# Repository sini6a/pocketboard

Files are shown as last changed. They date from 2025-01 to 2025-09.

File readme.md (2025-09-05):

# Pocketboard

### A Pocket-Friendly On-the-Go Keyboard 🖲️

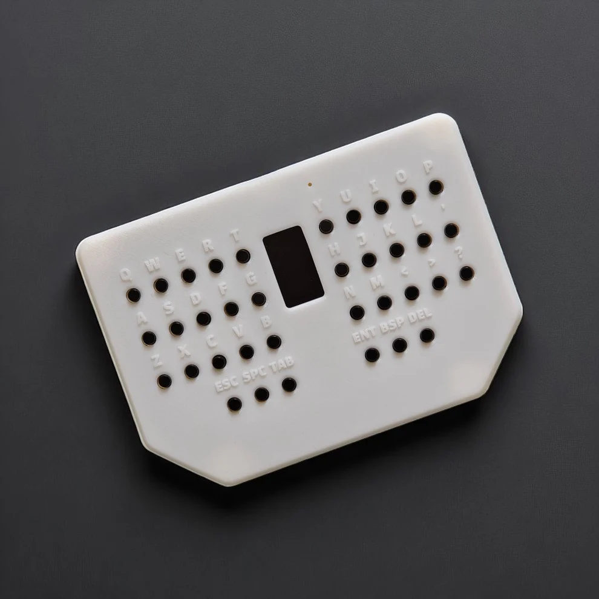
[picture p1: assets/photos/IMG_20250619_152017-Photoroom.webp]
Photo of the keyboard #1

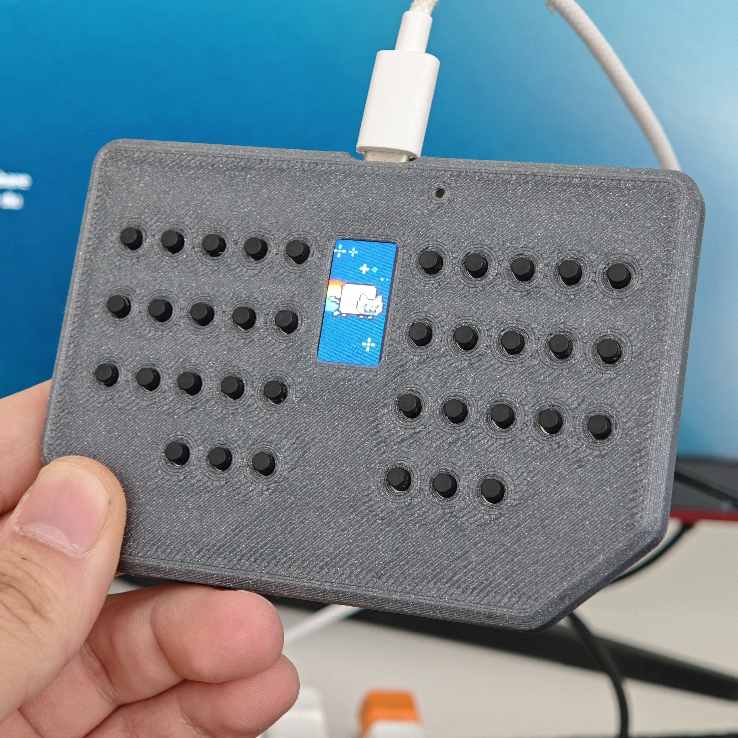
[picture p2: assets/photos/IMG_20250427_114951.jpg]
Photo of the keyboard #2


**Pocketboard** is a compact, versatile keyboard designed for IT technicians and professionals who need a portable and efficient input device.

**NOTE:** If you are building this keyboard and want to use KMK make sure to flash MicroPython for [Adafruit Feather RP2040](https://micropython.org/download/ADAFRUIT_FEATHER_RP2040/). After flashing just copy and paste the firmware located in the `firmware/kmk` folder. I recommend using the QMK firmware instead of KMK.

## Progress List:

- [x] Firmware: Home row mods!
- [x] Firmware: Layers
- [x] Firmware: LED Control (On/Off)
- [x] Hardware & Firmware: LCD!
- [x] 3D: Case Design

## Features

- **USB Type-C Connector**: Modern and reliable connection for seamless usage.
- **Miryoku Layout**: Optimized for productivity and efficient typing.
- **LEDs and Display**: Equipped with programmable LEDs and a display which shows pressed key and small animation when idle.

## What's New?

Pocketboard builds upon the original **HandiPi** design with several upgrades and enhancements:

- **ATMega328 replaced with RP2040**: Improved performance and more flexibility with the powerful RP2040 microcontroller.
- **LEDs for Illumination**: Added for better visibility.
- **USB Type-C Connector**: Ensures ease of connectivity and compatibility with modern devices.
- **LCD Support**: Added support for an LCD display for dynamic functionality. Tested and fully operational!
- **SMD Components**: Transitioned from through-hole components to SMD for a more compact design.

## Why Pocketboard?

Pocketboard is crafted for those who are often on the move, combining portability with practicality. Whether you're debugging systems or managing configurations, this handy keyboard ensures you're always prepared and comes handy to keep in your cargo pants or in your car.

## Project Structure

The project repository is structured as follows:

- **`kicad/`**: Contains PCB design files and schematics.
- **`gerbers/`**: Includes Gerber files essential for manufacturing.
- **`fimware/qmk`**: Includes Pocketboard firmware files. This folder should be copied to `qmk_firmware/keyboards`  before compiling.
- **`fimware/kmk`**: Includes Pocketboard firmware files. This folder should be copied to your keyboard after flashing MicroPython. (Not fully implemented!)

The schematic is available in PDF format in the `kicad/` directory.

## Credits

Pocketboard is inspired by the **HandiPi** project by [brickbots](https://github.com/brickbots).

## Contributing

We welcome contributions from the community! If you’re interested in helping with development, please:

1. Open an issue to discuss your ideas or proposed changes.
2. After discussion, submit a pull request (PR) with your contribution.

Your feedback and suggestions are invaluable in making Pocketboard even better!

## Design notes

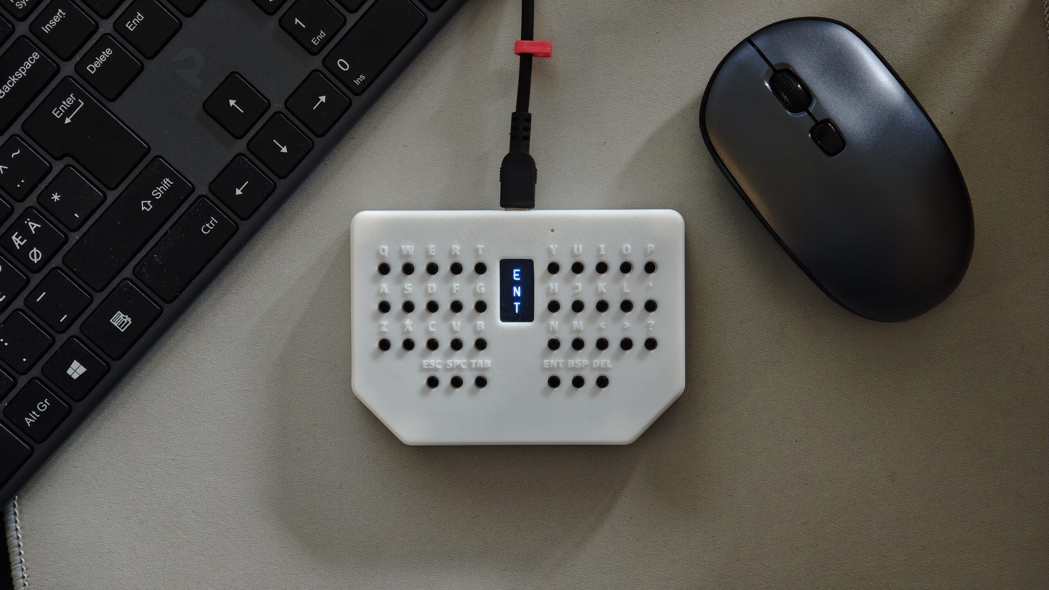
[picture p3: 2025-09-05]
assets/photos/IMG_20250607_135502-scaled.jpg

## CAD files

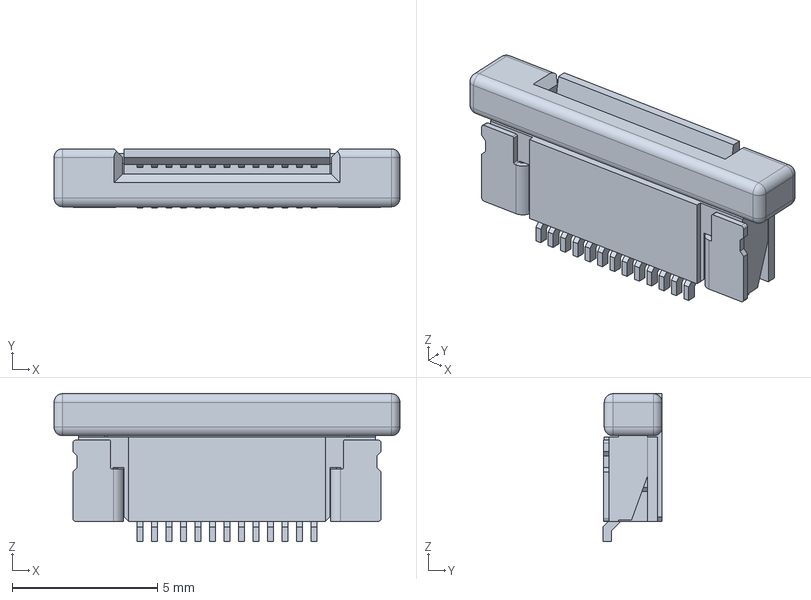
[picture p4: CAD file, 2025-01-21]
kicad/assets/models/1-1734839-3.stp
11.9 x 2.05 x 5.11 mm

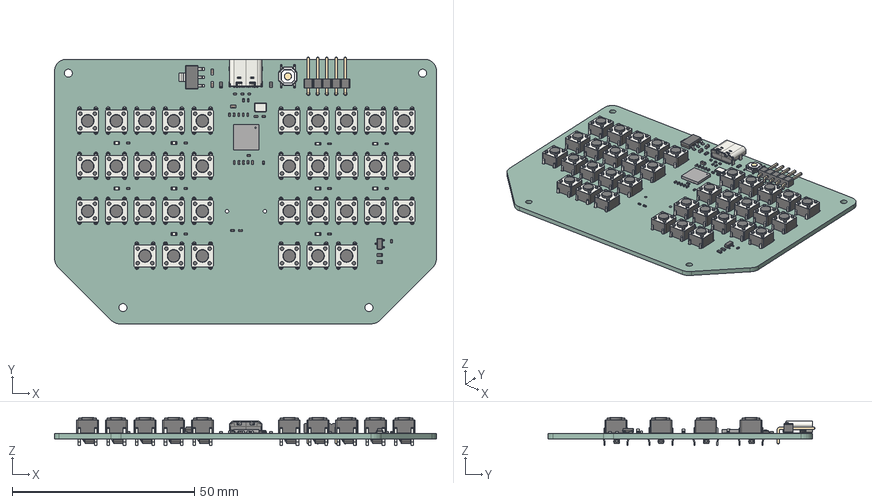
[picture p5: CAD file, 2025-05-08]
kicad/pocketboard.step
104.9 x 73.3 x 7.80 mm
R_0603_1608Metric x 4
SW_PUSH_6mm x 36
C_0402_1005Metric x 14
PinHeader_1x05_P2.54mm_Horizontal
LED_0603_1608Metric x 10
Crystal_SMD_3225-4Pin_3.2x2.5mm
R_0402_1005Metric x 15
D_SOD-923 x 3
C_0603_1608Metric x 3
USB_C_Receptacle_GCT_USB4105-xx-A_16P_TopMnt_Horizontal
QFN-56-1EP_7x7mm_P0.4mm_EP3.2x3.2mm
SOT-223
SOT-23
TS-1187A
D_SOD-123 x 36
pocketboard_PCB

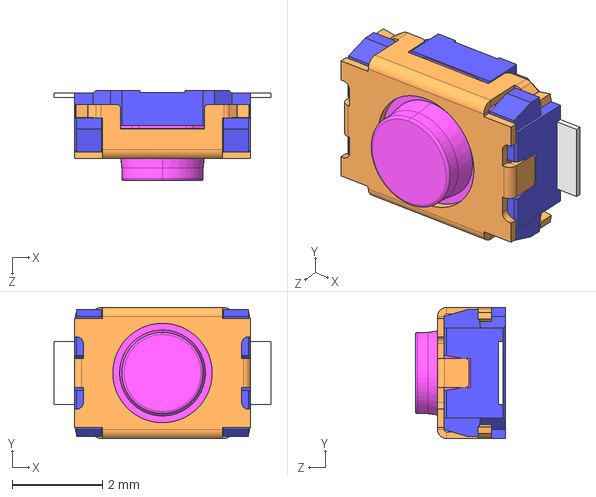
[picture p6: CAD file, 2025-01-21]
kicad/assets/models/SKRKAE.STEP
4.80 x 2.90 x 2.00 mm

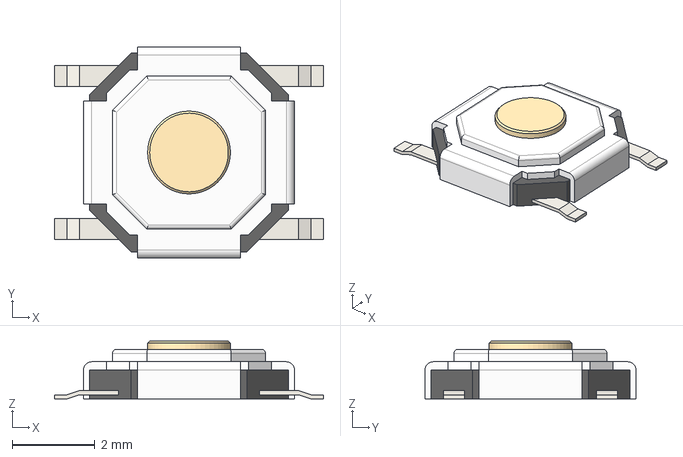
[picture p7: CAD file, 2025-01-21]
kicad/assets/models/TS-1187A.step
6.50 x 5.10 x 1.40 mm

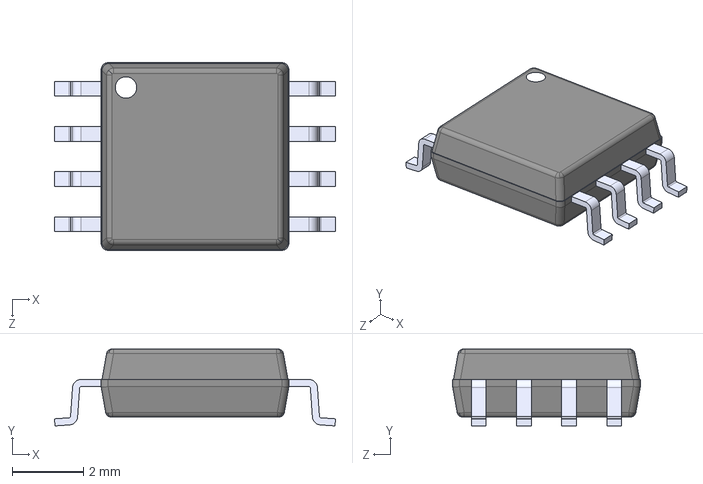
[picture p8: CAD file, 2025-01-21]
kicad/assets/models/W25Q128JVSIQ.STEP
7.90 x 2.16 x 5.28 mm

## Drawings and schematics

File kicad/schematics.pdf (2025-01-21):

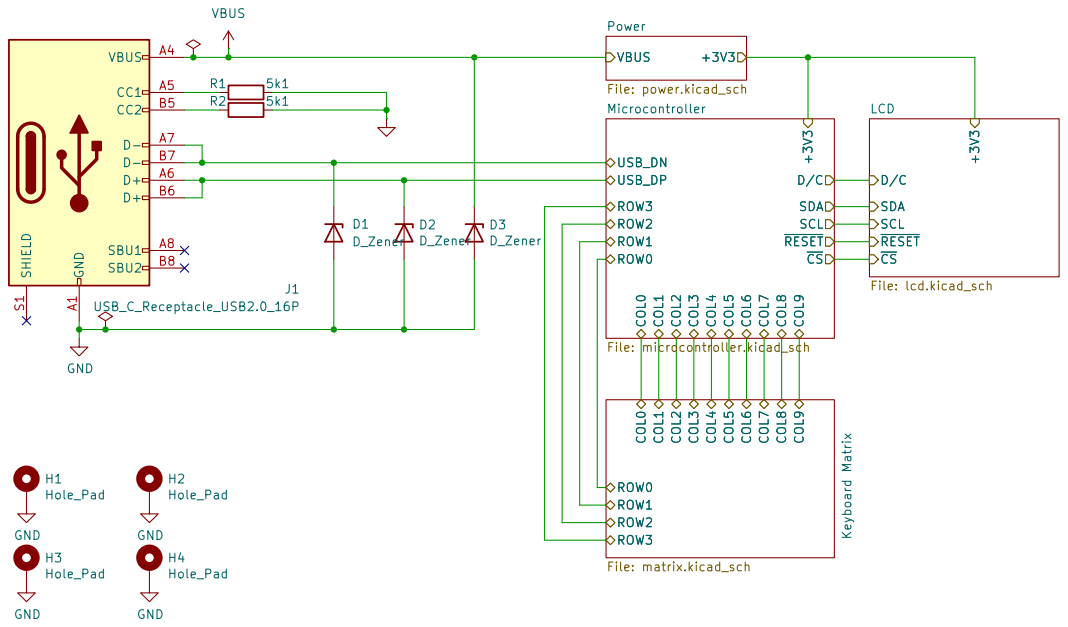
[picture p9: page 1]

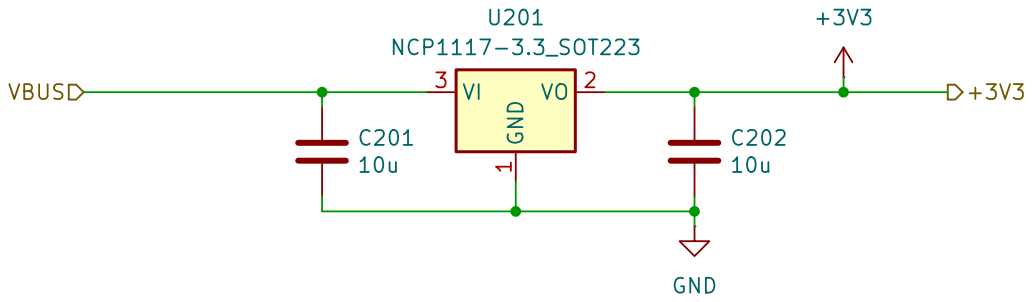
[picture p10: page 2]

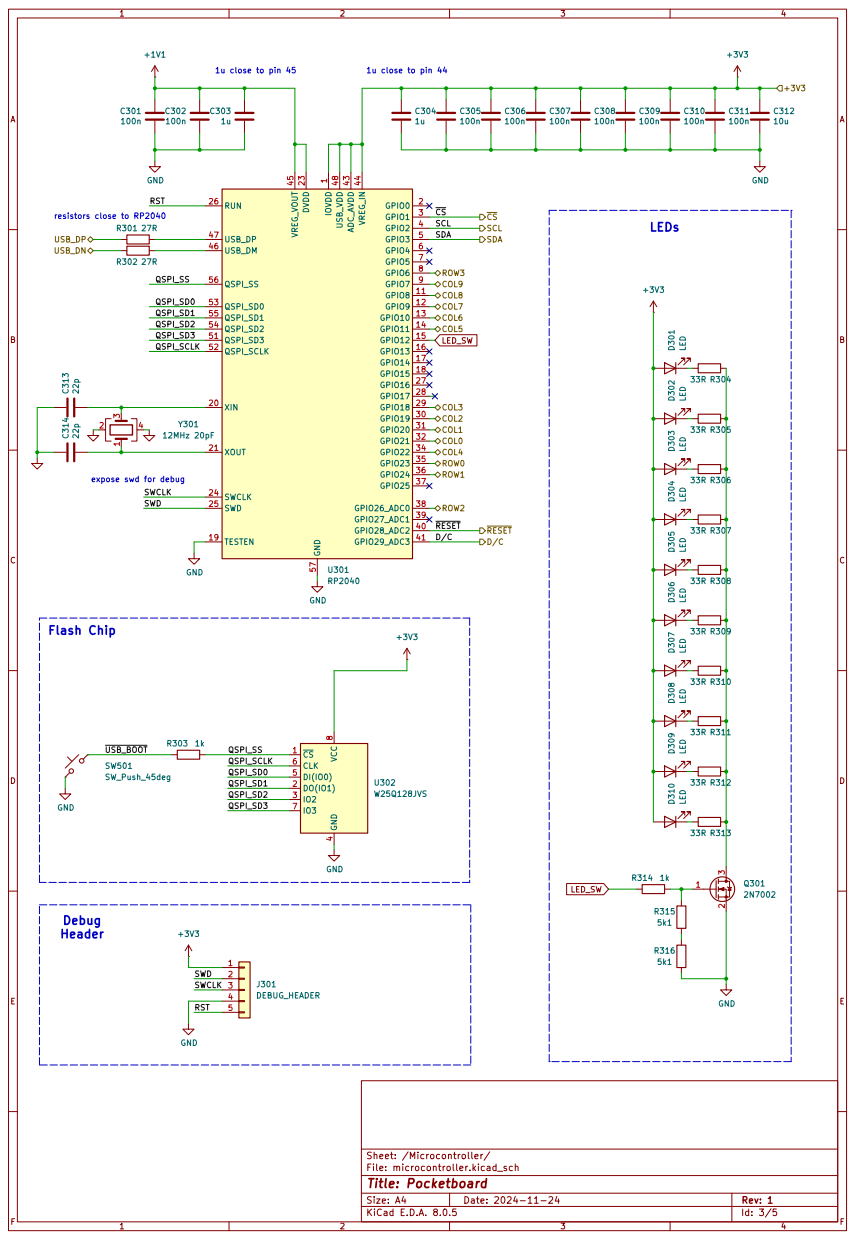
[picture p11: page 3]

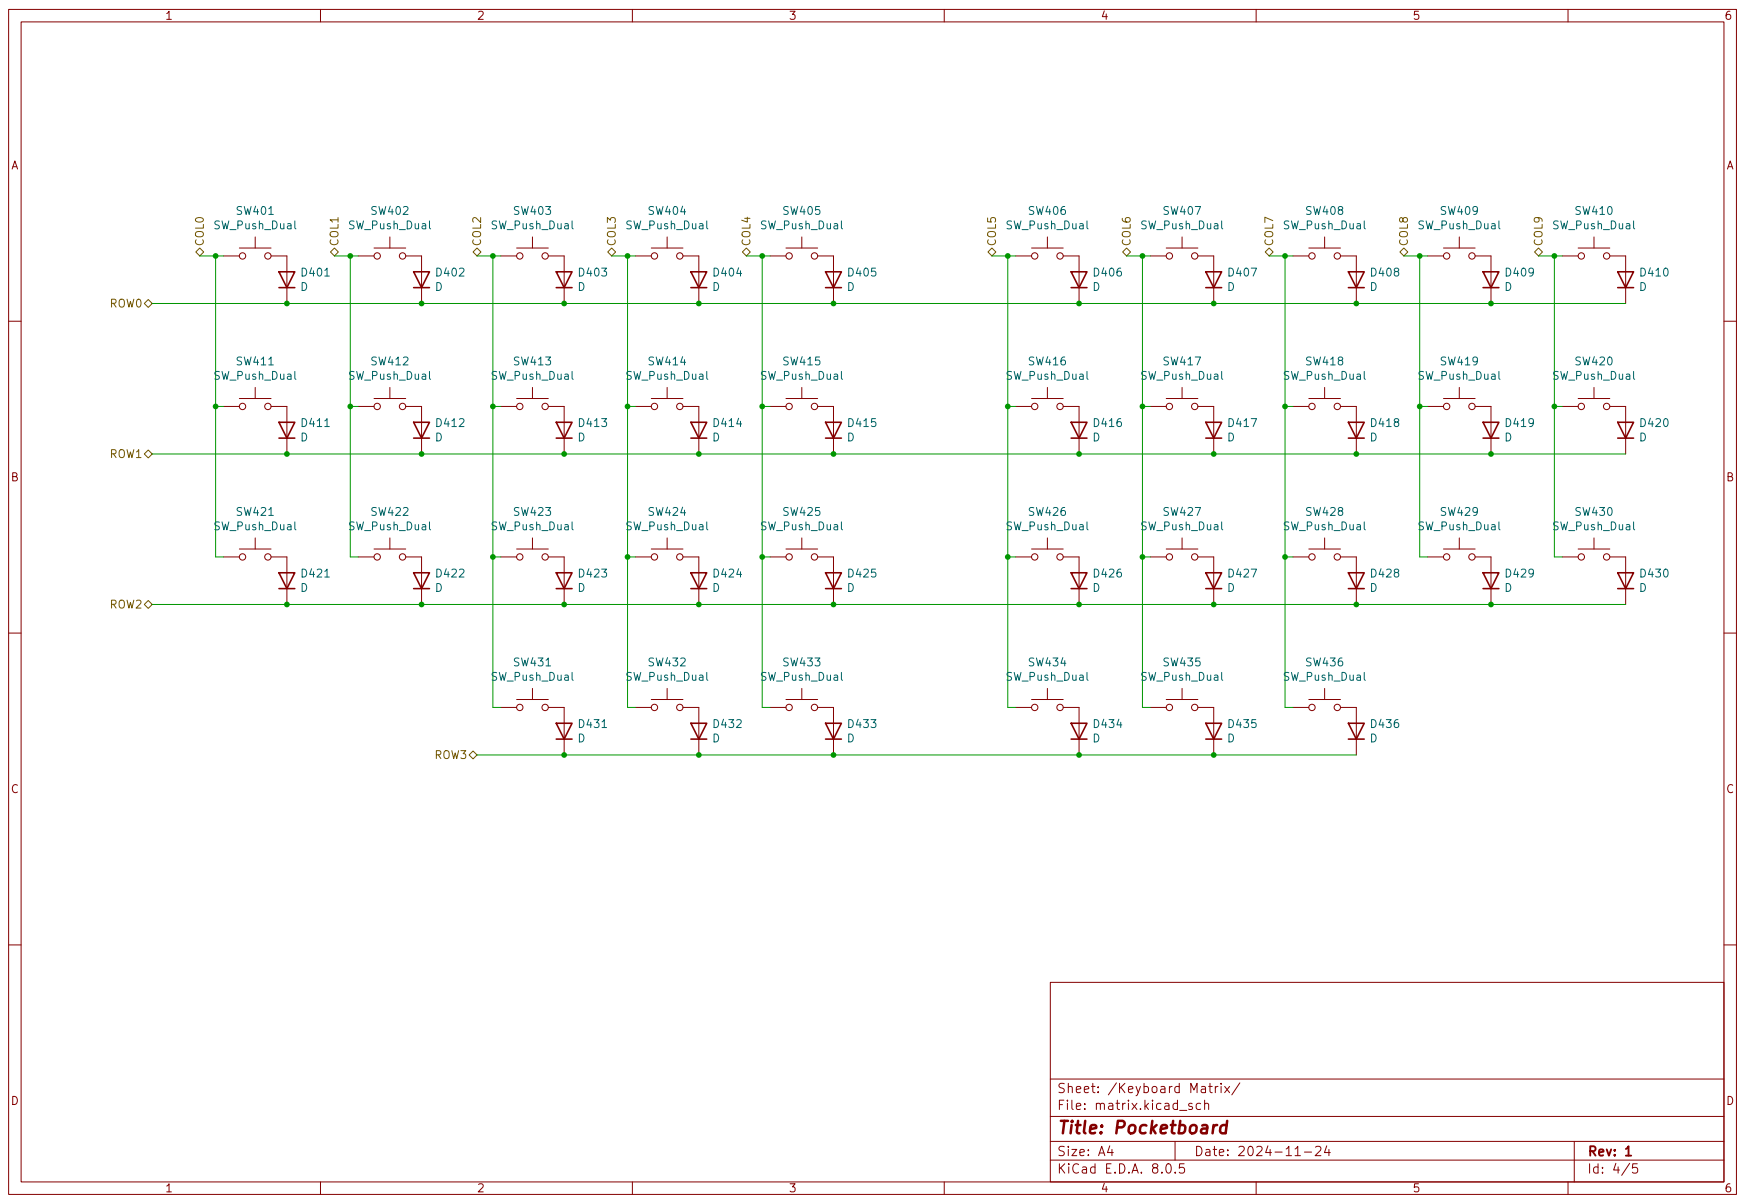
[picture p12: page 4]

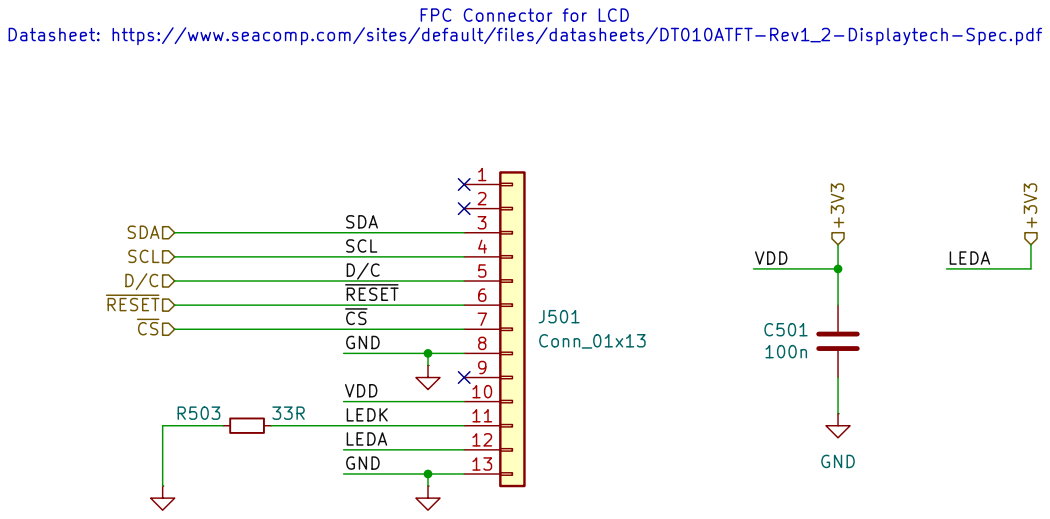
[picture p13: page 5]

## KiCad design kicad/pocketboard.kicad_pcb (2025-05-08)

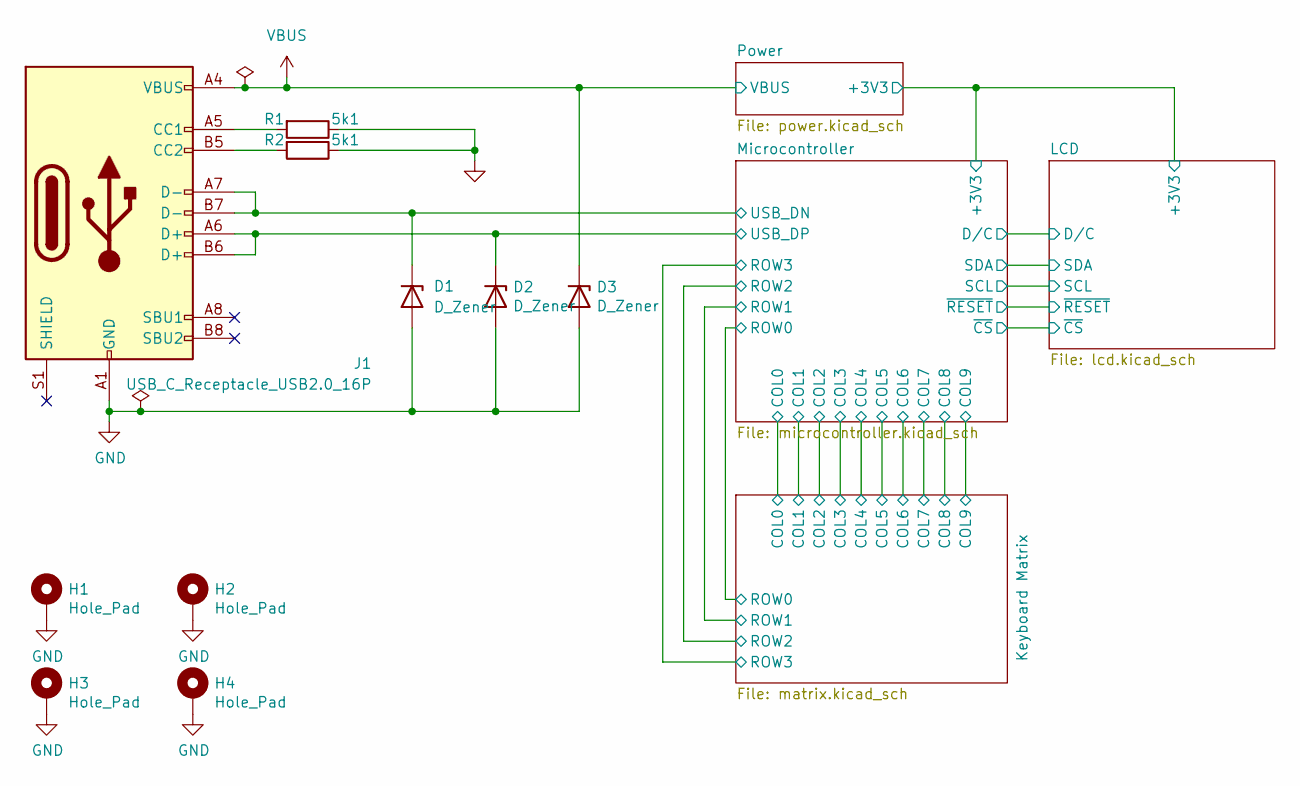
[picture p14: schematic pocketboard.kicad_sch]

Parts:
D1, D2, D3: D_Zener; D_SOD-923
H1, H2, H3, H4: Hole_Pad; MountingHole_2.2mm_M2_DIN965_Pad_TopBottom
J1: USB_C_Receptacle_USB2.0_16P; USB_C_Receptacle_GCT_USB4105-xx-A_16P_TopMnt_Horizontal; JLCPCB Part # C2927038
R1, R2: 5k1; R_0603_1608Metric; JLCPCB Part # C23186

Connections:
/Microcontroller/USB_DN: D1.1 (K), J1.A7 (D-), J1.B7 (D-); also elsewhere on the board
/Microcontroller/USB_DP: D2.1 (K), J1.A6 (D+), J1.B6 (D+); also elsewhere on the board
GND: D1.2 (A), D2.2 (A), D3.2 (A), H1.1, H2.1, H3.1, H4.1, J1.A1 (GND), J1.A12 (GND), J1.B1 (GND), J1.B12 (GND), R1.1, R2.1; also elsewhere on the board
unnamed: J1.A5 (CC1), R1.2
unnamed: J1.B5 (CC2), R2.2
VBUS: D3.1 (K), J1.A4 (VBUS), J1.A9 (VBUS), J1.B4 (VBUS), J1.B9 (VBUS); also elsewhere on the board

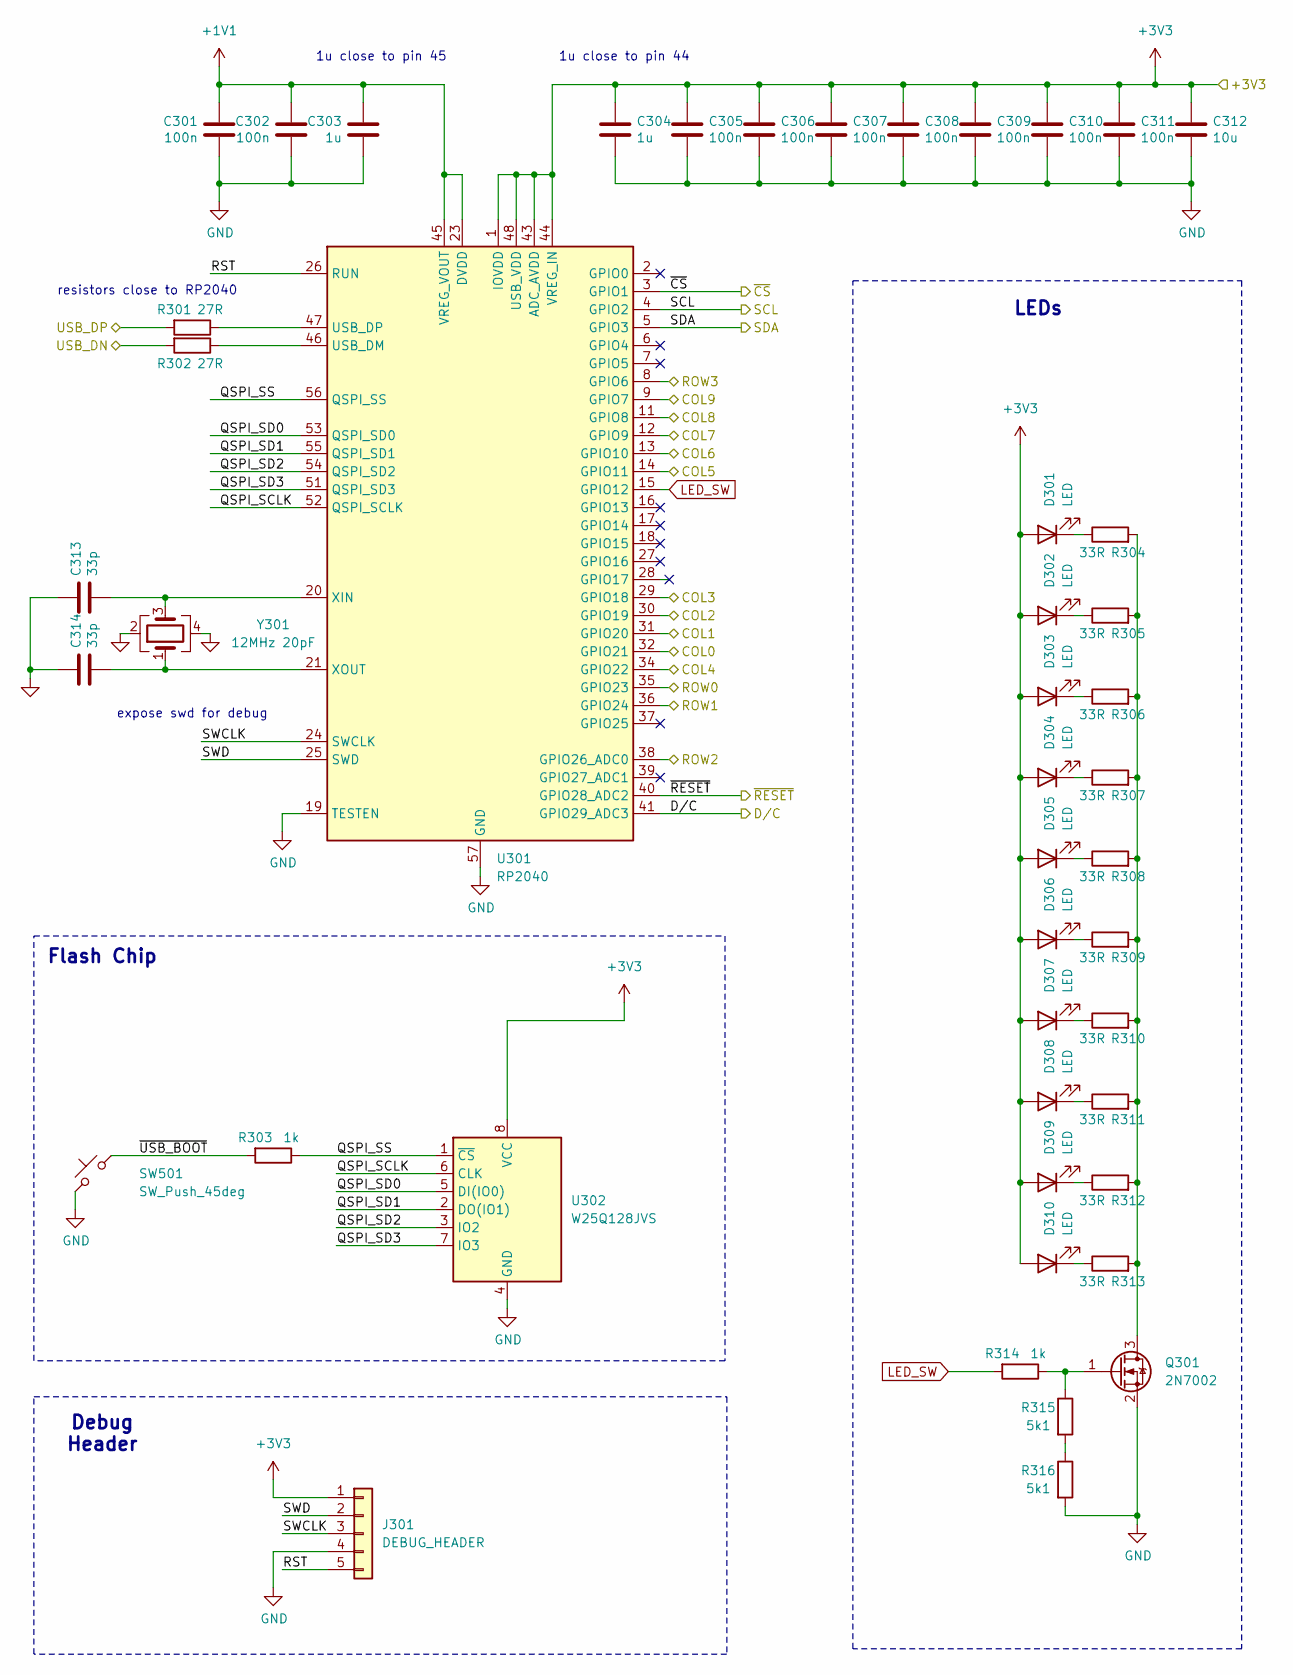
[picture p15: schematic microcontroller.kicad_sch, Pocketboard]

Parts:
C301, C302, C305, C306, C307, C308, C309, C310, C311: 100n; C_0402_1005Metric; JLCPCB Part # C1525
C303, C304: 1u; C_0402_1005Metric; JLCPCB Part # C52923
C312: 10u; C_0603_1608Metric; JLCPCB Part # C19702
C313, C314: 33p; C_0402_1005Metric; JLCPCB Part # C1562
D301, D302, D303, D304, D305, D306, D307, D308, D309, D310: LED; LED_0603_1608Metric; JLCPCB Part # C2290
J301: DEBUG_HEADER; PinHeader_1x05_P2.54mm_Horizontal
Q301: 2N7002; SOT-23; JLCPCB Part # C8545
R301, R302: 27R; R_0402_1005Metric; JLCPCB Part # C31439
R303, R314: 1k; R_0402_1005Metric; JLCPCB Part # C11702
R304, R305, R306, R307, R308, R309, R310, R311, R312, R313: 33R; R_0402_1005Metric; JLCPCB Part # C25105
R315, R316: 5k1; R_0603_1608Metric; JLCPCB Part # C23186
SW501: SW_Push_45deg; SW_Push_1P1T_XKB_TS-1187A; JLCPCB Part # C318884
U301: RP2040; QFN-56-1EP_7x7mm_P0.4mm_EP3.2x3.2mm; JLCPCB Part # C2040
U302: W25Q128JVS; SOIC-8_5.23x5.23mm_P1.27mm; JLCPCB Part # C97521
Y301: 12MHz 20pF; Crystal_SMD_3225-4Pin_3.2x2.5mm; JLCPCB Part # C9002

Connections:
+1V1: C301.1, C302.1, C303.1, U301.23 (DVDD), U301.45 (VREG_VOUT), U301.50 (DVDD)
+3V3: C304.1, C305.1, C306.1, C307.1, C308.1, C309.1, C310.1, C311.1, C312.1, D301.2 (A), D302.2 (A), D303.2 (A), D304.2 (A), D305.2 (A), D306.2 (A), D307.2 (A), D308.2 (A), D309.2 (A), D310.2 (A), J301.1, U301.1 (IOVDD), U301.10 (IOVDD), U301.22 (IOVDD), U301.33 (IOVDD), U301.42 (IOVDD), U301.43 (ADC_AVDD), U301.44 (VREG_IN), U301.48 (USB_VDD), U301.49 (IOVDD), U302.8 (VCC); also elsewhere on the board
/Keyboard Matrix/COL0: U301.32 (GPIO21); also elsewhere on the board
/Keyboard Matrix/COL1: U301.31 (GPIO20); also elsewhere on the board
/Keyboard Matrix/COL2: U301.30 (GPIO19); also elsewhere on the board
/Keyboard Matrix/COL3: U301.29 (GPIO18); also elsewhere on the board
/Keyboard Matrix/COL4: U301.34 (GPIO22); also elsewhere on the board
/Keyboard Matrix/COL5: U301.14 (GPIO11); also elsewhere on the board
/Keyboard Matrix/COL6: U301.13 (GPIO10); also elsewhere on the board
/Keyboard Matrix/COL7: U301.12 (GPIO9); also elsewhere on the board
/Keyboard Matrix/COL8: U301.11 (GPIO8); also elsewhere on the board
/Keyboard Matrix/COL9: U301.9 (GPIO7); also elsewhere on the board
/Keyboard Matrix/ROW0: U301.35 (GPIO23); also elsewhere on the board
/Keyboard Matrix/ROW1: U301.36 (GPIO24); also elsewhere on the board
/Keyboard Matrix/ROW2: U301.38 (GPIO26_ADC0); also elsewhere on the board
/Keyboard Matrix/ROW3: U301.8 (GPIO6); also elsewhere on the board
/LCD/D/C: U301.41 (GPIO29_ADC3); also elsewhere on the board
/LCD/SCL: U301.4 (GPIO2); also elsewhere on the board
/LCD/SDA: U301.5 (GPIO3); also elsewhere on the board
/LCD/~CS: U301.3 (GPIO1); also elsewhere on the board
/LCD/~RESET: U301.40 (GPIO28_ADC2); also elsewhere on the board
/Microcontroller/QSPI_SCLK: U301.52 (QSPI_SCLK), U302.6 (CLK)
/Microcontroller/QSPI_SD0: U301.53 (QSPI_SD0), U302.5 (DI(IO0))
/Microcontroller/QSPI_SD1: U301.55 (QSPI_SD1), U302.2 (DO(IO1))
/Microcontroller/QSPI_SD2: U301.54 (QSPI_SD2), U302.3 (IO2)
/Microcontroller/QSPI_SD3: U301.51 (QSPI_SD3), U302.7 (IO3)
/Microcontroller/QSPI_SS: R303.1, U301.56 (QSPI_SS), U302.1 (~CS)
/Microcontroller/RST: J301.5, U301.26 (RUN)
/Microcontroller/SWCLK: J301.3, U301.24 (SWCLK)
/Microcontroller/SWD: J301.2, U301.25 (SWD)
/Microcontroller/USB_DN: R302.2; also elsewhere on the board
/Microcontroller/USB_DP: R301.2; also elsewhere on the board
/Microcontroller/~USB_BOOT: R303.2, SW501.2
GND: C301.2, C302.2, C303.2, C304.2, C305.2, C306.2, C307.2, C308.2, C309.2, C310.2, C311.2, C312.2, C313.1, C314.1, J301.4, Q301.2 (S), R316.2, SW501.1, U301.19 (TESTEN), U301.57 (GND), U302.4 (GND), Y301.2, Y301.4; also elsewhere on the board
LED_SW: R314.2, U301.15 (GPIO12)
unnamed: D301.1 (K), R304.1
unnamed: D302.1 (K), R305.1
unnamed: D303.1 (K), R306.1
unnamed: D304.1 (K), R307.1
unnamed: D305.1 (K), R308.1
unnamed: D306.1 (K), R309.1
unnamed: D307.1 (K), R310.1
unnamed: D308.1 (K), R311.1
unnamed: D309.1 (K), R312.1
unnamed: D310.1 (K), R313.1
unnamed: Q301.3 (D), R304.2, R305.2, R306.2, R307.2, R308.2, R309.2, R310.2, R311.2, R312.2, R313.2
unnamed: Q301.1 (G), R314.1, R315.1
unnamed: R315.2, R316.1
unnamed: R302.1, U301.46 (USB_DM)
unnamed: R301.1, U301.47 (USB_DP)
unnamed: C313.2, U301.20 (XIN), Y301.3
unnamed: C314.2, U301.21 (XOUT), Y301.1

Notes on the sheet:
Flash Chip
1u close to pin 44
1u close to pin 45
expose swd for debug
Debug Header
LEDs
resistors close to RP2040

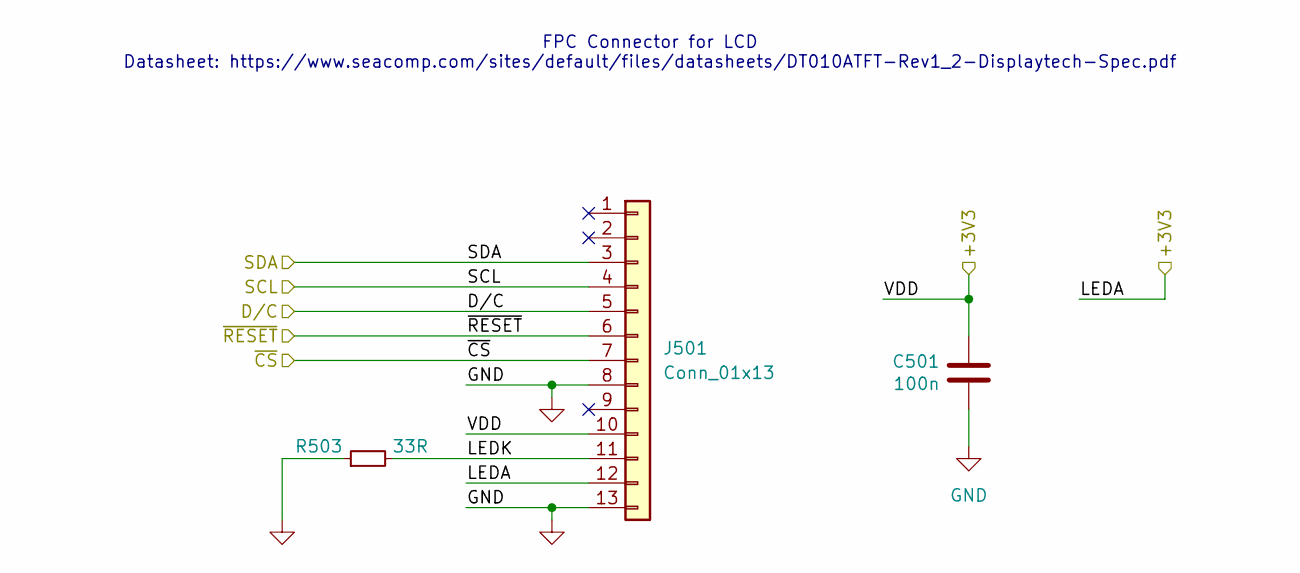
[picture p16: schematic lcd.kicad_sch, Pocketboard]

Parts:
C501: 100n; C_0402_1005Metric; JLCPCB Part # C1525
J501: Conn_01x13; N096-1608TBBIG11-H13; JLCPCB Part # C2890616
R503: 33R; R_0402_1005Metric; JLCPCB Part # C25105

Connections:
+3V3: C501.1, J501.10, J501.12; also elsewhere on the board
/LCD/D/C: J501.5; also elsewhere on the board
/LCD/LEDK: J501.11, R503.2
/LCD/SCL: J501.4; also elsewhere on the board
/LCD/SDA: J501.3; also elsewhere on the board
/LCD/~CS: J501.7; also elsewhere on the board
/LCD/~RESET: J501.6; also elsewhere on the board
GND: C501.2, J501.8, J501.13, R503.1; also elsewhere on the board

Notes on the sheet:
FPC Connector for LCD Datasheet: https://www.seacomp.com/sites/default/files/datasheets/DT010ATFT-Rev1_2-Displaytech-Spec.pdf

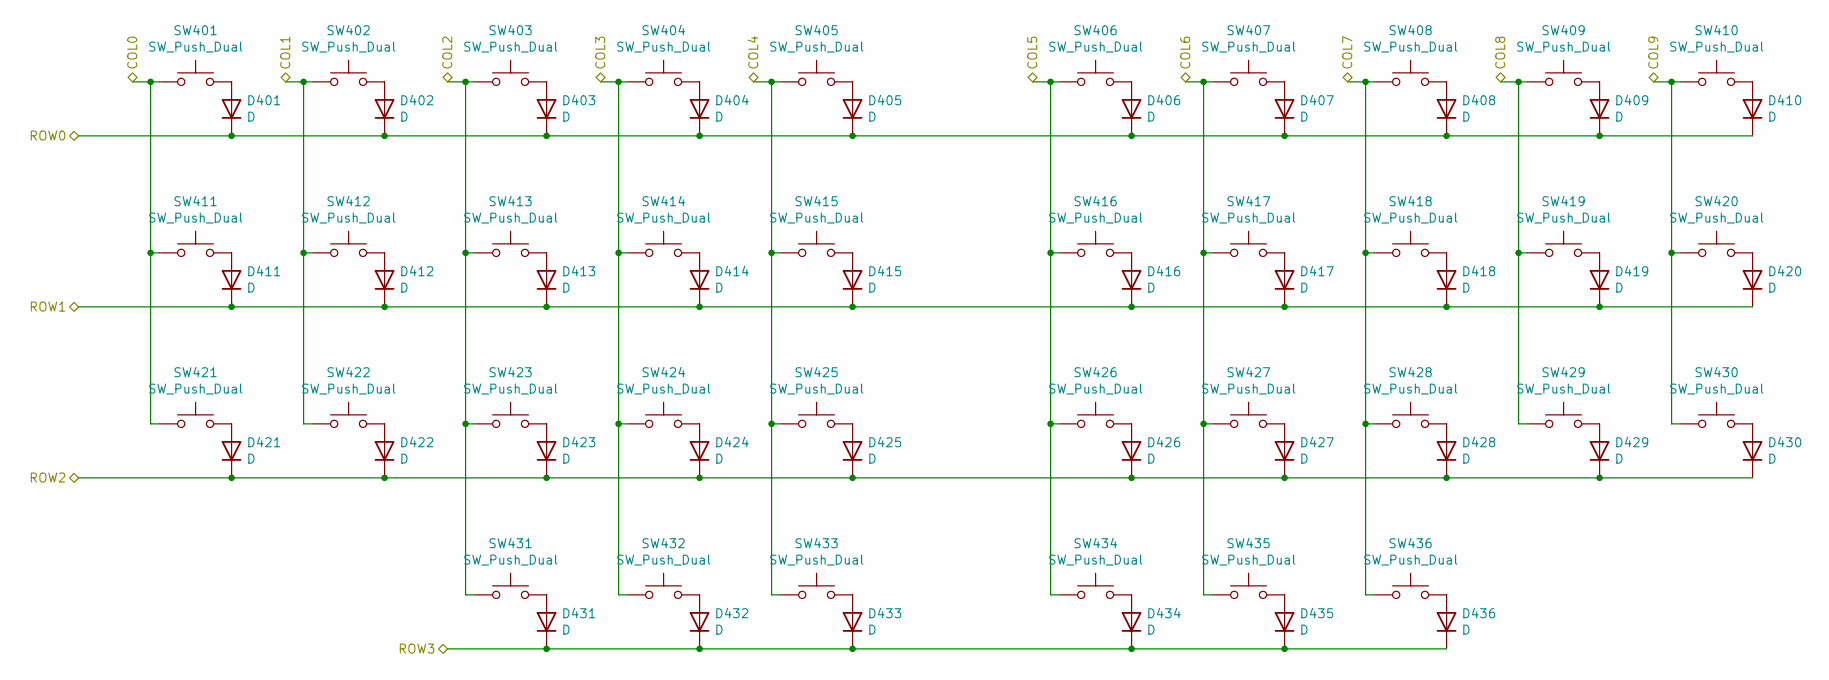
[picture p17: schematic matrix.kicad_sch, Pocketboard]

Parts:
D401, D402, D403, D404, D405, D406, D407, D408, D409, D410, D411, D412, D413, D414, D415, D416, D417, D418, D419, D420, D421, D422, D423, D424, D425, D426, D427, D428, D429, D430, D431, D432, D433, D434, D435, D436: D; D_SOD-123; JLCPCB Part # C81598
SW401, SW402, SW403, SW404, SW405, SW406, SW407, SW408, SW409, SW410, SW411, SW412, SW413, SW414, SW415, SW416, SW417, SW418, SW419, SW420, SW421, SW422, SW423, SW424, SW425, SW426, SW427, SW428, SW429, SW430, SW431, SW432, SW433, SW434, SW435, SW436: SW_Push_Dual; SW_PUSH_6mm; JLCPCB Part # C455095

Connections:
/Keyboard Matrix/COL0: SW401.1, SW411.1, SW421.1; also elsewhere on the board
/Keyboard Matrix/COL1: SW402.1, SW412.1, SW422.1; also elsewhere on the board
/Keyboard Matrix/COL2: SW403.1, SW413.1, SW423.1, SW431.1; also elsewhere on the board
/Keyboard Matrix/COL3: SW404.1, SW414.1, SW424.1, SW432.1; also elsewhere on the board
/Keyboard Matrix/COL4: SW405.1, SW415.1, SW425.1, SW433.1; also elsewhere on the board
/Keyboard Matrix/COL5: SW406.1, SW416.1, SW426.1, SW434.1; also elsewhere on the board
/Keyboard Matrix/COL6: SW407.1, SW417.1, SW427.1, SW435.1; also elsewhere on the board
/Keyboard Matrix/COL7: SW408.1, SW418.1, SW428.1, SW436.1; also elsewhere on the board
/Keyboard Matrix/COL8: SW409.1, SW419.1, SW429.1; also elsewhere on the board
/Keyboard Matrix/COL9: SW410.1, SW420.1, SW430.1; also elsewhere on the board
/Keyboard Matrix/ROW0: D401.1 (K), D402.1 (K), D403.1 (K), D404.1 (K), D405.1 (K), D406.1 (K), D407.1 (K), D408.1 (K), D409.1 (K), D410.1 (K); also elsewhere on the board
/Keyboard Matrix/ROW1: D411.1 (K), D412.1 (K), D413.1 (K), D414.1 (K), D415.1 (K), D416.1 (K), D417.1 (K), D418.1 (K), D419.1 (K), D420.1 (K); also elsewhere on the board
/Keyboard Matrix/ROW2: D421.1 (K), D422.1 (K), D423.1 (K), D424.1 (K), D425.1 (K), D426.1 (K), D427.1 (K), D428.1 (K), D429.1 (K), D430.1 (K); also elsewhere on the board
/Keyboard Matrix/ROW3: D431.1 (K), D432.1 (K), D433.1 (K), D434.1 (K), D435.1 (K), D436.1 (K); also elsewhere on the board
unnamed: D401.2 (A), SW401.2
unnamed: D402.2 (A), SW402.2
unnamed: D403.2 (A), SW403.2
unnamed: D404.2 (A), SW404.2
unnamed: D405.2 (A), SW405.2
unnamed: D406.2 (A), SW406.2
unnamed: D407.2 (A), SW407.2
unnamed: D408.2 (A), SW408.2
unnamed: D409.2 (A), SW409.2
unnamed: D410.2 (A), SW410.2
unnamed: D411.2 (A), SW411.2
unnamed: D412.2 (A), SW412.2
unnamed: D413.2 (A), SW413.2
unnamed: D414.2 (A), SW414.2
unnamed: D415.2 (A), SW415.2
unnamed: D416.2 (A), SW416.2
unnamed: D417.2 (A), SW417.2
unnamed: D418.2 (A), SW418.2
unnamed: D419.2 (A), SW419.2
unnamed: D420.2 (A), SW420.2
unnamed: D421.2 (A), SW421.2
unnamed: D422.2 (A), SW422.2
unnamed: D423.2 (A), SW423.2
unnamed: D424.2 (A), SW424.2
unnamed: D425.2 (A), SW425.2
unnamed: D426.2 (A), SW426.2
unnamed: D427.2 (A), SW427.2
unnamed: D428.2 (A), SW428.2
unnamed: D429.2 (A), SW429.2
unnamed: D430.2 (A), SW430.2
unnamed: D431.2 (A), SW431.2
unnamed: D432.2 (A), SW432.2
unnamed: D433.2 (A), SW433.2
unnamed: D434.2 (A), SW434.2
unnamed: D435.2 (A), SW435.2
unnamed: D436.2 (A), SW436.2

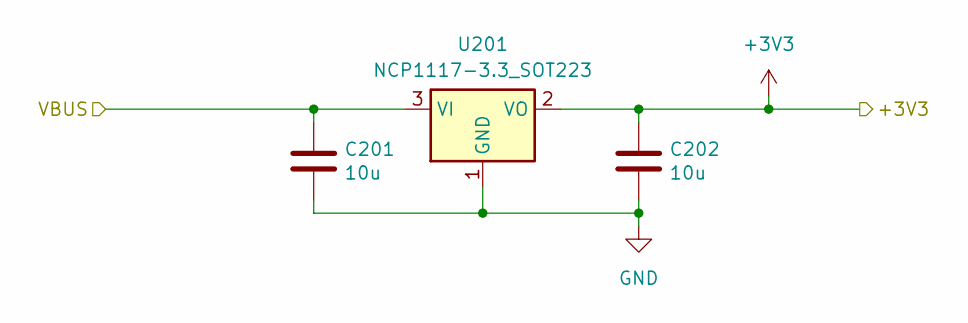
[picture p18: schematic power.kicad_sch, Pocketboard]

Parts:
C201, C202: 10u; C_0603_1608Metric; JLCPCB Part # C19702
U201: NCP1117-3.3_SOT223; SOT-223; JLCPCB Part # C6186

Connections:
+3V3: C202.1, U201.2 (VO); also elsewhere on the board
GND: C201.2, C202.2, U201.1 (GND); also elsewhere on the board
VBUS: C201.1, U201.3 (VI); also elsewhere on the board

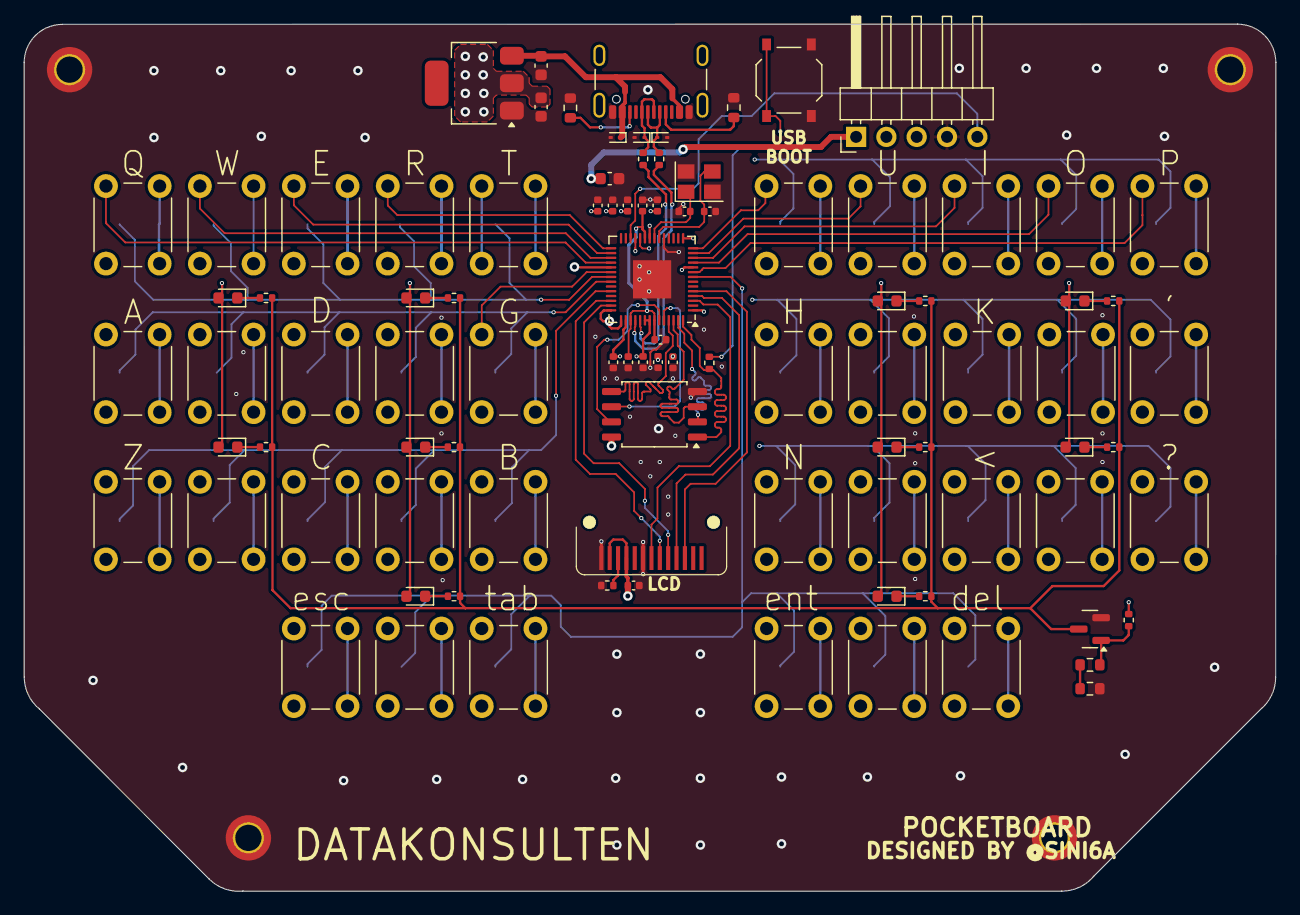
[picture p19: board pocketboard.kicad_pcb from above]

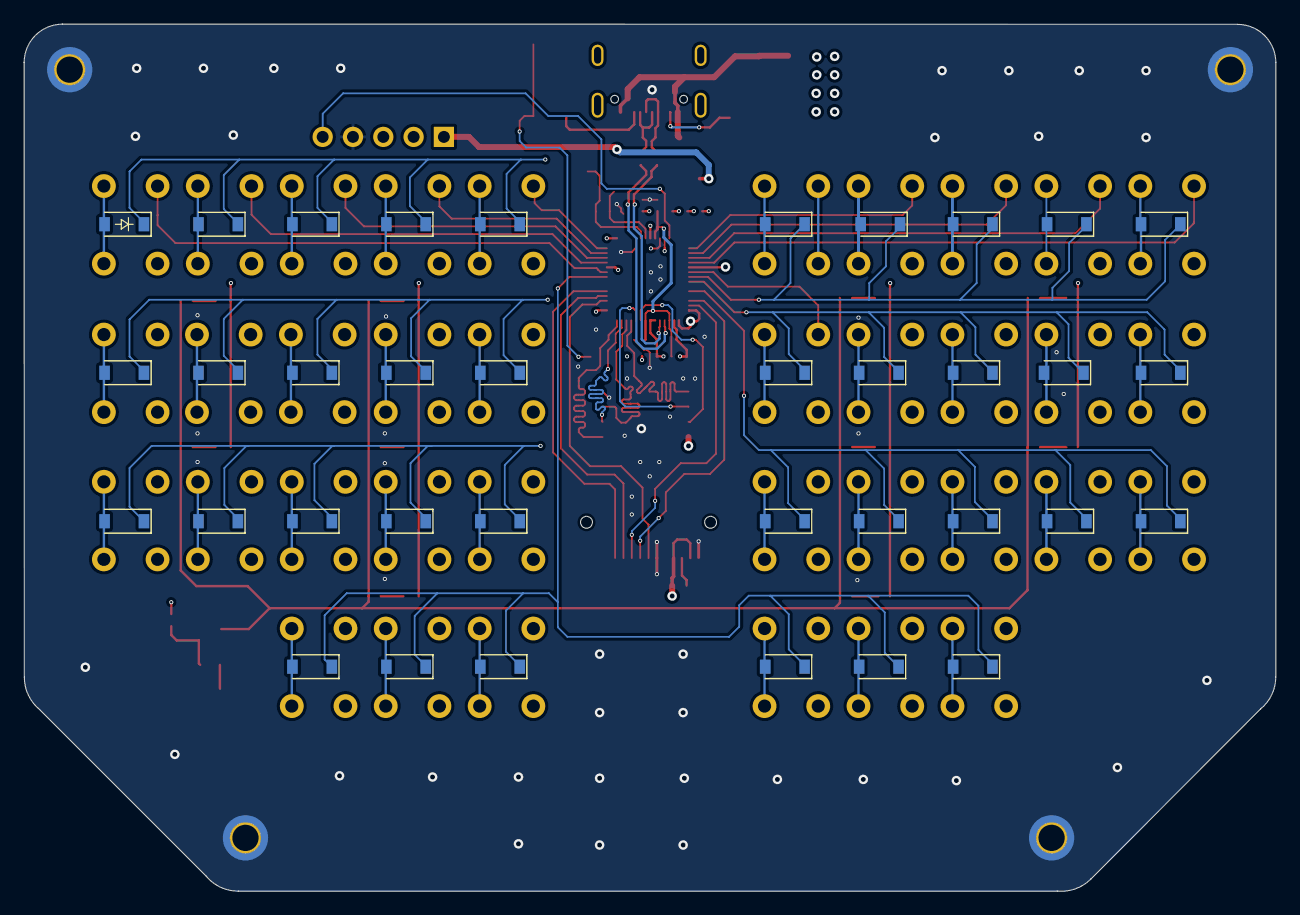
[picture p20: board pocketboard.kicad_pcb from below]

Board: 4 copper layers, 104.9 x 72.7 mm, 134 parts (36 on the bottom side), 92 nets.

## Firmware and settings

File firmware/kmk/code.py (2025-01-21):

import microcontroller.pin as board # type: ignore
import digitalio
from kmk.kmk_keyboard import KMKKeyboard
from kmk.keys import KC
from kmk.scanners import DiodeOrientation
from kmk.modules.layers import Layers

print("Starting")

keyboard = KMKKeyboard()
keyboard.modules.append(Layers())

# Define the GPIO pin you want to control
pin_to_toggle = digitalio.DigitalInOut(board.GPIO12)  # Replace with your pin number
pin_to_toggle.direction = digitalio.Direction.OUTPUT
pin_to_toggle.value = True  # Start with the pin LOW

# Define your keyboard matrix and configuration
keyboard.col_pins = (
    board.GPIO21, board.GPIO20, board.GPIO19, board.GPIO18, board.GPIO22,
    board.GPIO11, board.GPIO10, board.GPIO9, board.GPIO8, board.GPIO7
)
keyboard.row_pins = (
    board.GPIO23, board.GPIO24, board.GPIO26, board.GPIO6
)
keyboard.diode_orientation = DiodeOrientation.ROW2COL

# Define the keymap
keyboard.keymap = [
    [
        KC.Q                , KC.W                , KC.E               , KC.R               , KC.T                  , KC.Y              , KC.U               , KC.I               , KC.O                , KC.P,
        KC.A                , KC.S                , KC.D               , KC.F               , KC.G                  , KC.H              , KC.J               , KC.K               , KC.L                , KC.SCLN,
        KC.Z                , KC.X                , KC.C               , KC.V               , KC.B                  , KC.N              , KC.M               , KC.COMMA           , KC.DOT              , KC.SLSH,
        KC.NO               , KC.NO               , KC.ESC             , KC.SPC             , KC.TAB                , KC.ENTER          , KC.BACKSPACE       , KC.DEL             , KC.NO               , KC.NO
    ],
]

if __name__ == '__main__':
    keyboard.go()

"""     [1] = LAYOUT_qwerty( // nav layer
        KC_NO,      KC_NO,   KC_NO,   KC_NO,   KC_NO,   KC_NO,         KC_NO,   KC_NO,   KC_NO,   KC_NO,   KC_NO,             KC_NO,
        KC_NO,         KC_NO,   KC_NO,   KC_NO,   KC_NO,   KC_NO,         KC_AGIN,   KC_PASTE,   KC_COPY,   KC_CUT,   KC_UNDO,             KC_NO,
        KC_NO,  KC_LGUI,   KC_LALT,   KC_LCTL,   KC_LSFT,   KC_NO,         KC_CAPS,   KC_LEFT,   KC_DOWN,   KC_UP,   KC_RIGHT,     KC_NO,
        KC_NO,   KC_NO,   KC_NO,   KC_NO,   KC_NO,   KC_NO,         KC_INS,   KC_HOME,   KC_PAGE_DOWN,   KC_PAGE_UP,   KC_END,    KC_NO,
                                   KC_NO, KC_NO, KC_NO,         KC_ENTER, KC_BACKSPACE, KC_DELETE
    ),
    [2] = LAYOUT_qwerty( // function layer
        QK_BOOT,      KC_F1,   KC_F2,   KC_F3,   KC_F4,   KC_F5,         KC_F6,   KC_F7,   KC_F8,   KC_F9,   KC_F10,             KC_NO,
        KC_NO,     KC_F12,   KC_F7,   KC_F8,   KC_F9,   KC_PSCR,         KC_NO,   KC_NO,   KC_NO,   KC_F11,   KC_F12,             KC_NO,
        KC_NO,     KC_F11,   KC_F4,   KC_F5,   KC_F6,   KC_SCRL,         KC_NO,   KC_RSFT,   KC_RCTL,   KC_RALT,   KC_RGUI,     KC_NO,
        KC_NO,     KC_F10,   KC_F1,   KC_F2,   KC_F3,   KC_PAUS,         KC_NO,   KC_NO,   KC_NO,   KC_NO,   KC_NO,    KC_NO,
                                         KC_APP, KC_SPC, KC_TAB,         KC_NO, KC_NO, KC_NO
    ),
    [3] = LAYOUT_qwerty( // number layer
        KC_NO,      KC_NO,   KC_NO,   KC_NO,   KC_NO,   KC_NO,         KC_NO,   KC_NO,   KC_NO,   KC_NO,   KC_NO,             KC_NO,
        KC_NO,     KC_LBRC,   KC_7,   KC_8,   KC_9,   KC_RCBR,         KC_NO,   KC_NO,   KC_NO,   KC_NO,   KC_NO,             KC_NO,
        KC_NO,     KC_SCLN,   KC_4,   KC_5,   KC_6,   KC_EQL,         KC_NO,   KC_RSFT,   KC_RCTL,   KC_RALT,   KC_RGUI,     KC_NO,
        KC_NO,     KC_COMM,   KC_1,   KC_2,   KC_3,   KC_BSLS,         KC_NO,   KC_NO,   KC_NO,   KC_NO,   KC_NO,    KC_NO,
                                         KC_DOT, KC_0, KC_MINUS,         KC_NO, KC_NO, KC_NO
    ),
    [4] = LAYOUT_qwerty( // symbol layer
        KC_NO,      KC_NO,   KC_NO,   KC_NO,   KC_NO,   KC_NO,         KC_NO,   KC_NO,   KC_NO,   KC_NO,   KC_NO,             KC_NO,
        KC_NO,     KC_LCBR,   KC_AMPR,   KC_ASTR,   KC_LPRN,   KC_RCBR,         KC_NO,   KC_NO,   KC_NO,   KC_NO,   KC_NO,             KC_NO,
        KC_NO,     KC_COLN,   KC_DLR,   KC_PERC,   KC_CIRC,   KC_PLUS,         KC_NO,   KC_RSFT,   KC_RCTL,   KC_RALT,   KC_RGUI,     KC_NO,
        KC_NO,     KC_TILD,   KC_EXLM,   KC_AT,   KC_HASH,   KC_PIPE,         KC_NO,   KC_NO,   KC_NO,   KC_NO,   KC_NO,    KC_NO,
                                         KC_LPRN, KC_RPRN, KC_UNDS,         KC_NO, KC_NO, KC_NO
    ),
    [5] = LAYOUT_qwerty( // media layer
        KC_NO,      KC_NO,   KC_NO,   KC_NO,   KC_NO,   KC_NO,         KC_NO,   KC_NO,   KC_NO,   KC_NO,   KC_NO,             KC_NO,
        KC_NO,     KC_NO,   KC_NO,   KC_NO,   KC_NO,   KC_NO,         RGB_TOG,   RGB_MOD,   RGB_HUI,   RGB_SAI,   RGB_VAI,             KC_NO,
        KC_NO,     KC_LGUI,   KC_LALT,   KC_LCTL,   KC_LSFT,   KC_NO,         KC_NO,   KC_MPRV,   KC_VOLD,   KC_VOLU,   KC_MNXT,     KC_NO,
        KC_NO,     KC_NO,   KC_NO,   KC_NO,   KC_NO,   KC_NO,         KC_NO,   KC_NO,   KC_NO,   KC_NO,   KC_NO,             KC_NO,
                                         KC_NO, KC_NO, KC_NO,         KC_MSTP, KC_MPLY, KC_MUTE
    ),
    [6] = LAYOUT_qwerty( // mouse layer
        KC_NO,      KC_NO,   KC_NO,   KC_NO,   KC_NO,   KC_NO,         KC_NO,   KC_NO,   KC_NO,   KC_NO,   KC_NO,             KC_NO,
        KC_NO,         KC_NO,   KC_NO,   KC_NO,   KC_NO,   KC_NO,         KC_AGIN,   KC_PASTE,   KC_COPY,   KC_CUT,   KC_UNDO,             KC_NO,
        KC_NO,  KC_LGUI,   KC_LALT,   KC_LCTL,   KC_LSFT,   KC_NO,         KC_NO,   KC_MS_L,   KC_MS_D,   KC_MS_U,   KC_MS_R,     KC_NO,
        KC_NO,   KC_NO,   KC_NO,   KC_NO,   KC_NO,   KC_NO,         KC_NO,   KC_WH_L,   KC_WH_D,   KC_WH_U,   KC_WH_R,    KC_NO,
                                   KC_NO, KC_NO, KC_NO,         KC_BTN2, KC_BTN1, KC_BTN3
    )
 """

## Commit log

2025-01-21 initial release
    [1-1734839-3.stp, SKRKAE.STEP, TS-1187A.step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]
2025-05-08 Updated to KiCad 9
    [lcd.kicad_sch, matrix.kicad_sch, microcontroller.kicad_sch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]
2026-11-11 updated 3d models to be compatible with kicad 10
2026-11-11 updated schematic for KiCad 10
2026-11-11 stop tracking KiCad local history
2026-11-11 Added assembly fixture for tactile buttons
